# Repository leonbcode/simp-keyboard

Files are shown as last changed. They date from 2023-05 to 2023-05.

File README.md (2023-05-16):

# SIMP - Simple Macropad

SIMP is a simple macropad designed to optimize task automation. It features a 4x4 key matrix and an OLED display.

## About

SIMP is a hobby project that allows me to learn about microcontrollers and embedded systems. The project aims to create a simple and versatile macropad to enhance productivity. It's important to note that SIMP is a personal project developed for educational purposes. As I'm learning and improving my skills in microcontrollers and embedded systems, SIMP will evolve.

## Features

- 4x4 key matrix 
- OLED display 
- USB-C
- Compact and simple design

## Firmware

I am actively developing a dedicated firmware specifically for SIMP, which can be accessed at [simp-firmware](https://github.com/leonbcode/simp-firmware).

*Please be aware that the firmware is still a work in progress and primarily serves as a learning experience in embedded development.*

## License

This project is licensed under the [MIT License](LICENSE).

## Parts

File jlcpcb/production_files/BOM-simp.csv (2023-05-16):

Comment | Designator | Footprint | LCSC
ATmega32U4-M | U1 | QFN-44-1EP_7x7mm_P0.5mm_EP5.2x5.2mm | C112161
16MHz | Y1 | Crystal_SMD_3225-4Pin_3.2x2.5mm | C13738
1u | C1 | C_0603_1608Metric | C15849
100n | C4,C5,C6,C7 | C_0603_1608Metric | C1591
22p | C2,C3 | C_0603_1608Metric | C1653
USB_C_Receptacle_USB2.0 | J3 | USB_C_Receptacle_HRO_TYPE-C-31-M-12 | C165948
D_Schottky | D17 | D_SOD-123F | C169540
10u | C8 | C_0603_1608Metric | C19702
22 | R5,R6 | R_0603_1608Metric | C22775
5.1k | R3,R4 | R_0603_1608Metric | C23186
10k | R1,R2 | R_0603_1608Metric | C25804
500mA | F1 | Fuse_0805_2012Metric | C269104
USBLC6-2P6 | U2 | SOT-666 | C2827693
D | D1,D10,D11,D12,D13,D14,D15,D16,D2,D3,D4,D5,D6,D7,D8,D9 | D_SOD-123 | C81598
MX_SW_solder | SW7 | SW_MX_1u
MX_SW_solder | SW12 | SW_MX_1u
MX_SW_solder | SW11 | SW_MX_1u
MX_SW_solder | SW15 | SW_MX_1u
MX_SW_solder | SW5 | SW_MX_1u
MX_SW_solder | SW1 | SW_MX_1u
MX_SW_solder | SW9 | SW_MX_1u
MX_SW_solder | SW16 | SW_MX_1u
MX_SW_solder | SW3 | SW_MX_1u
MX_SW_solder | SW4 | SW_MX_1u
MX_SW_solder | SW6 | SW_MX_1u
MX_SW_solder | SW2 | SW_MX_1u
MX_SW_solder | SW10 | SW_MX_1u
MX_SW_solder | SW14 | SW_MX_1u
MX_SW_solder | SW8 | SW_MX_1u
MX_SW_solder | SW13 | SW_MX_1u
I2C | J2 | PinSocket_1x04_P2.54mm_Vertical
AVR-ISP-6 | J1 | PinSocket_2x03_P2.54mm_Vertical

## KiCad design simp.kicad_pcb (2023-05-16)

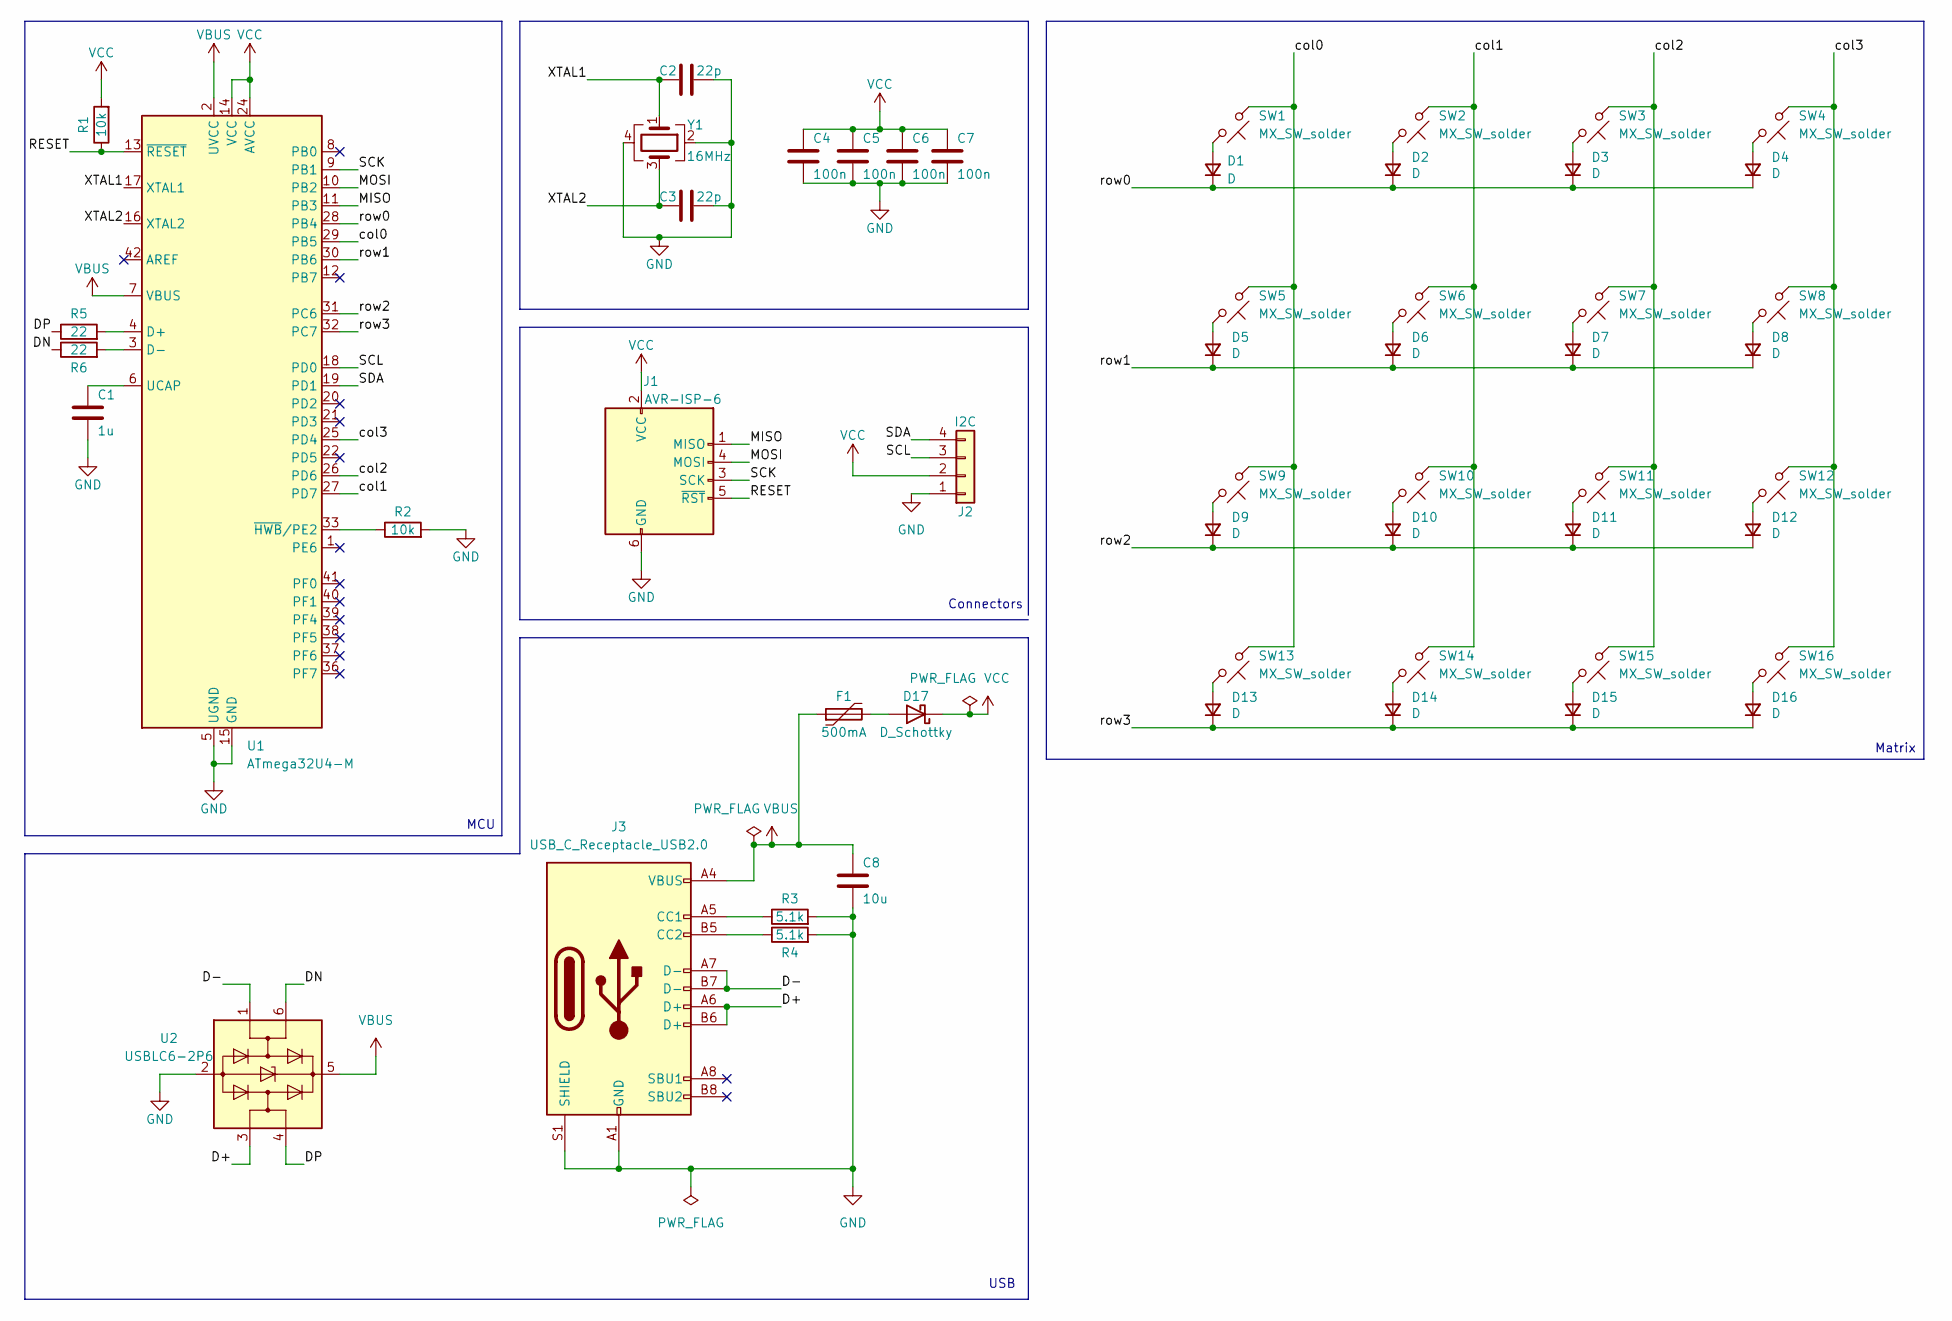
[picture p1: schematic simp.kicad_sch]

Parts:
C1: 1u; C_0603_1608Metric
C2, C3: 22p; C_0603_1608Metric
C4, C5, C6, C7: 100n; C_0603_1608Metric
C8: 10u; C_0603_1608Metric
D1, D2, D3, D4, D5, D6, D7, D8, D9, D10, D11, D12, D13, D14, D15, D16: D; D_SOD-123; LCSC C81598
D17: D_Schottky; D_SOD-123F
F1: 500mA; Fuse_0805_2012Metric
J1: AVR-ISP-6; PinSocket_2x03_P2.54mm_Vertical
J2: I2C; PinSocket_1x04_P2.54mm_Vertical
J3: USB_C_Receptacle_USB2.0; USB_C_Receptacle_HRO_TYPE-C-31-M-12
R1, R2: 10k; R_0603_1608Metric
R3, R4: 5.1k; R_0603_1608Metric
R5, R6: 22; R_0603_1608Metric
SW1, SW2, SW3, SW4, SW5, SW6, SW7, SW8, SW9, SW10, SW11, SW12, SW13, SW14, SW15, SW16: MX_SW_solder; SW_MX_1u
U1: ATmega32U4-M; QFN-44-1EP_7x7mm_P0.5mm_EP5.2x5.2mm
U2: USBLC6-2P6; SOT-666
Y1: 16MHz; Crystal_SMD_3225-4Pin_3.2x2.5mm

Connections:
/D+: J3.A6 (D+), J3.B6 (D+), U2.3 (I/O2)
/D-: J3.A7 (D-), J3.B7 (D-), U2.1 (I/O1)
/DN: R6.1, U2.6 (I/O1)
/DP: R5.1, U2.4 (I/O2)
/MISO: J1.1 (MISO), U1.11 (PB3)
/MOSI: J1.4 (MOSI), U1.10 (PB2)
/RESET: J1.5 (~RST), R1.1, U1.13 (~RESET)
/SCK: J1.3 (SCK), U1.9 (PB1)
/SCL: J2.3, U1.18 (PD0)
/SDA: J2.4, U1.19 (PD1)
/XTAL1: C2.1, U1.17 (XTAL1), Y1.1
/XTAL2: C3.1, U1.16 (XTAL2), Y1.3
/col0: SW1.1, SW5.1, SW9.1, SW13.1, U1.29 (PB5)
/col1: SW2.1, SW6.1, SW10.1, SW14.1, U1.27 (PD7)
/col2: SW3.1, SW7.1, SW11.1, SW15.1, U1.26 (PD6)
/col3: SW4.1, SW8.1, SW12.1, SW16.1, U1.25 (PD4)
/row0: D1.1 (K), D2.1 (K), D3.1 (K), D4.1 (K), U1.28 (PB4)
/row1: D5.1 (K), D6.1 (K), D7.1 (K), D8.1 (K), U1.30 (PB6)
/row2: D9.1 (K), D10.1 (K), D11.1 (K), D12.1 (K), U1.31 (PC6)
/row3: D13.1 (K), D14.1 (K), D15.1 (K), D16.1 (K), U1.32 (PC7)
GND: C1.2, C2.2, C3.2, C4.2, C5.2, C6.2, C7.2, C8.2, J1.6 (GND), J2.1, J3.A1 (GND), J3.A12 (GND), J3.B1 (GND), J3.B12 (GND), J3.S1 (SHIELD), R2.2, R3.2, R4.2, U1.5 (UGND), U1.15 (GND), U1.23 (GND), U1.35 (GND), U1.43 (GND), U1.45 (GND), U2.2 (GND), Y1.2, Y1.4
unnamed: C1.1, U1.6 (UCAP)
unnamed: D1.2 (A), SW1.2
unnamed: D2.2 (A), SW2.2
unnamed: D3.2 (A), SW3.2
unnamed: D4.2 (A), SW4.2
unnamed: D5.2 (A), SW5.2
unnamed: D6.2 (A), SW6.2
unnamed: D7.2 (A), SW7.2
unnamed: D8.2 (A), SW8.2
unnamed: D9.2 (A), SW9.2
unnamed: D10.2 (A), SW10.2
unnamed: D11.2 (A), SW11.2
unnamed: D12.2 (A), SW12.2
unnamed: D13.2 (A), SW13.2
unnamed: D14.2 (A), SW14.2
unnamed: D15.2 (A), SW15.2
unnamed: D16.2 (A), SW16.2
unnamed: D17.2 (A), F1.2
unnamed: J3.A5 (CC1), R3.1
unnamed: J3.B5 (CC2), R4.1
unnamed: R2.1, U1.33 (~HWB/PE2)
unnamed: R5.2, U1.4 (D+)
unnamed: R6.2, U1.3 (D-)
VBUS: C8.1, F1.1, J3.A4 (VBUS), J3.A9 (VBUS), J3.B4 (VBUS), J3.B9 (VBUS), U1.2 (UVCC), U1.7 (VBUS), U2.5 (VBUS)
VCC: C4.1, C5.1, C6.1, C7.1, D17.1 (K), J1.2 (VCC), J2.2, R1.2, U1.14 (VCC), U1.24 (AVCC), U1.34 (VCC), U1.44 (AVCC)

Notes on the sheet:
Matrix
Connectors
USB
MCU

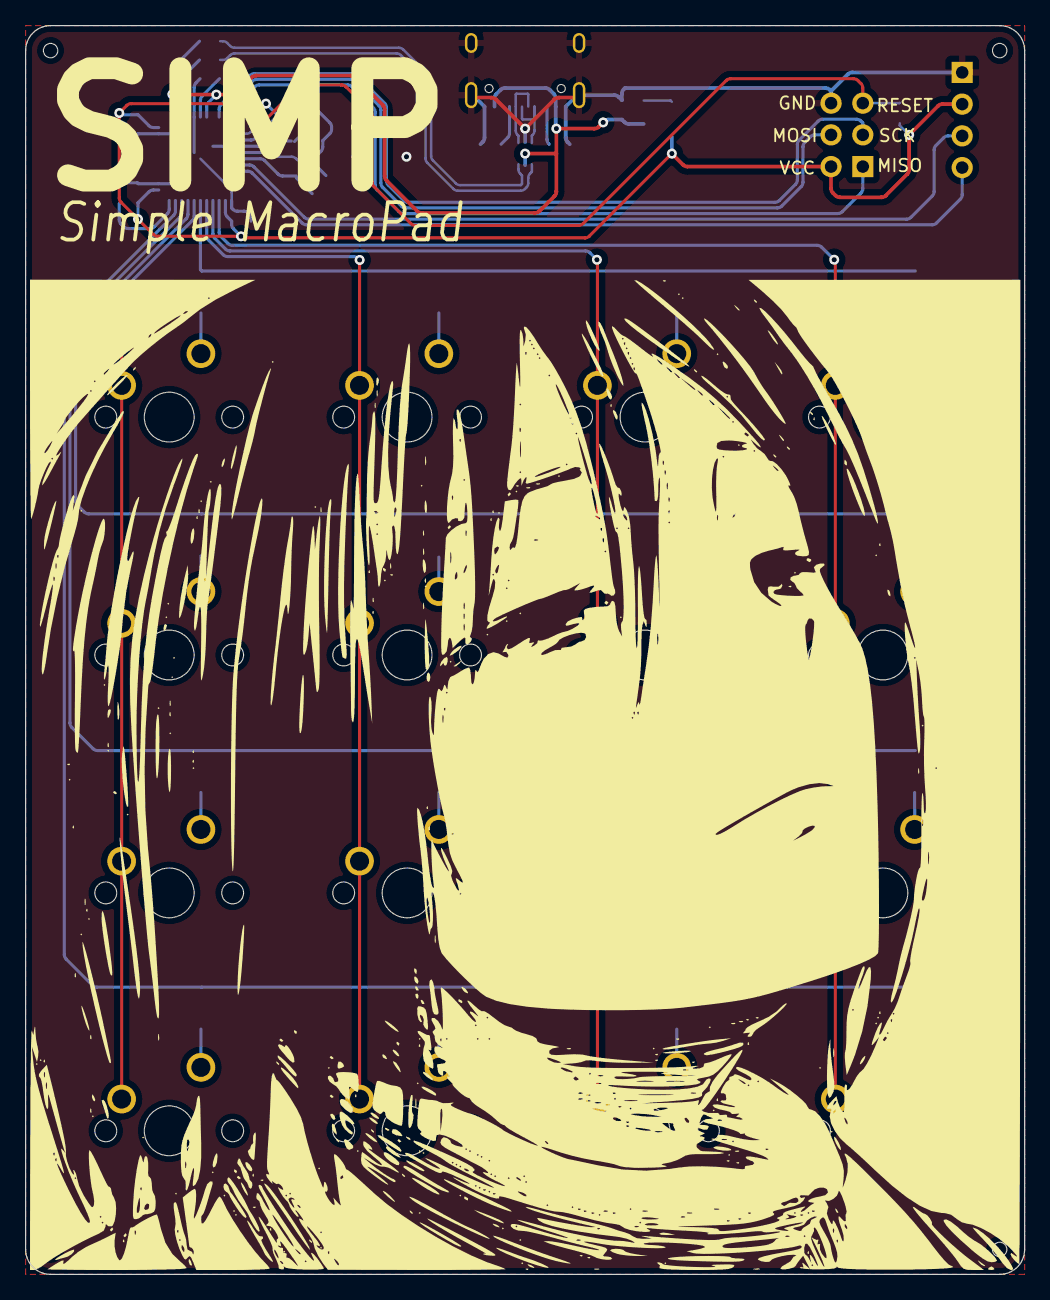
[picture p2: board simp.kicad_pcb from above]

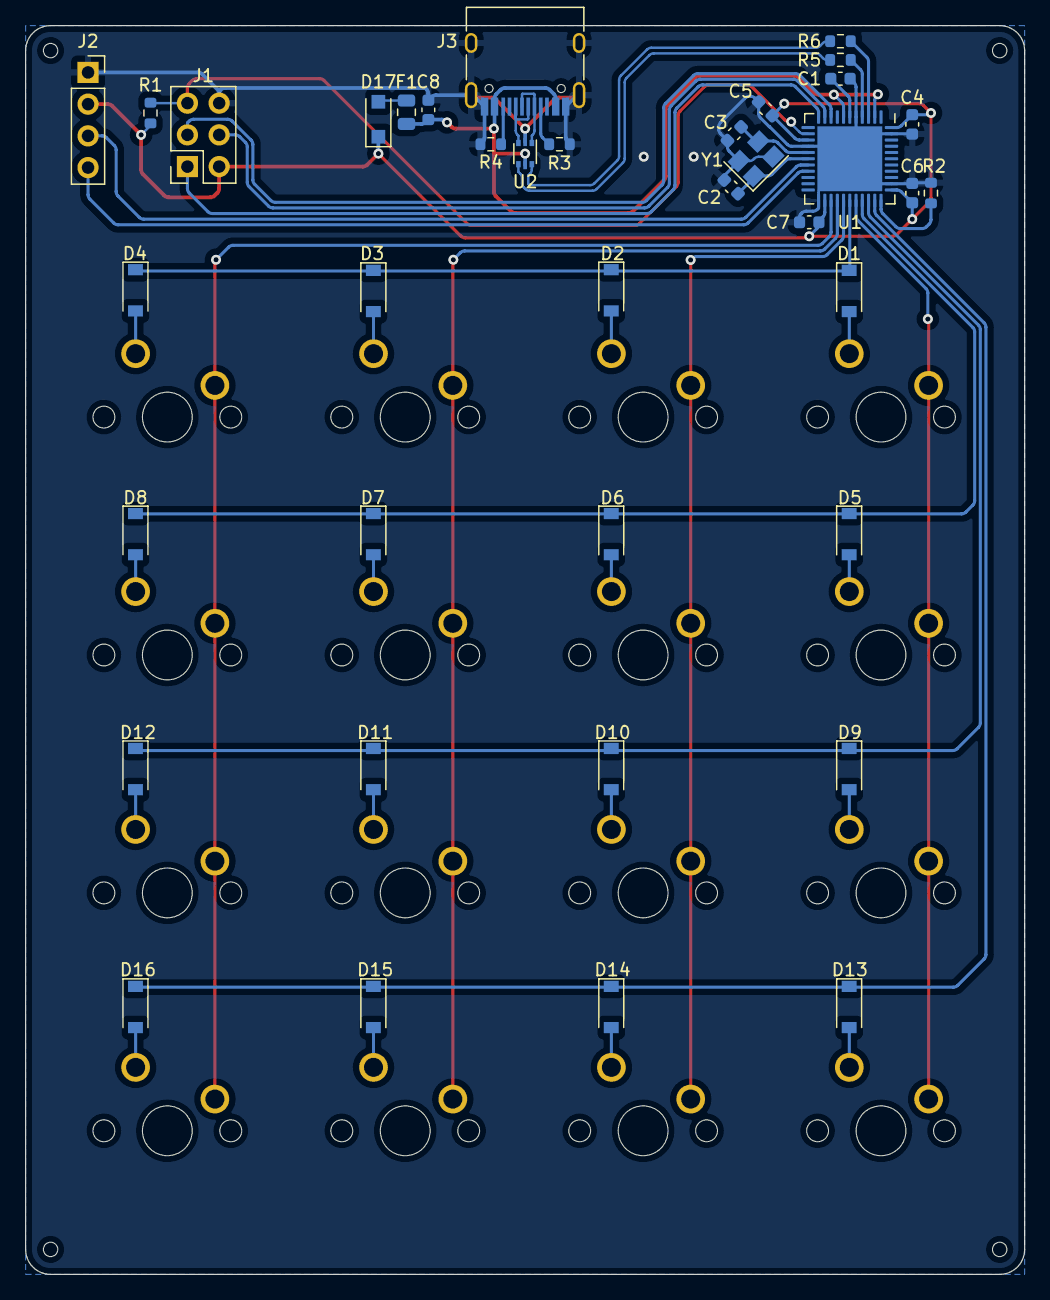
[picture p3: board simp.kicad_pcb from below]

Board: 2 copper layers, 80.0 x 100.0 mm, 54 parts (38 on the bottom side), 46 nets.

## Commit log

2023-05-16 add project files
    [BOM-simp.csv, simp.kicad_pcb, simp.kicad_sch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]
2023-05-16 version: bump version to 1.0.0
    [simp.kicad_pcb, simp.kicad_sch]
